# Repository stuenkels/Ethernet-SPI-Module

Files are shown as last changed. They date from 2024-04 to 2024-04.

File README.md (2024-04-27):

# Ethernet SPI Module based on the ENC28J60 IC
Validating my ethernet hardware design. I will use this ethernet board layout in a much larger project, just wanted to test my design and make sure it works.

This board was manufactured by PCBWay, I had it produced for free. I recomend PCBWay to anyone needing PCB or even PCBA production services. Go to pcbway.com for more details. 

## 3d View
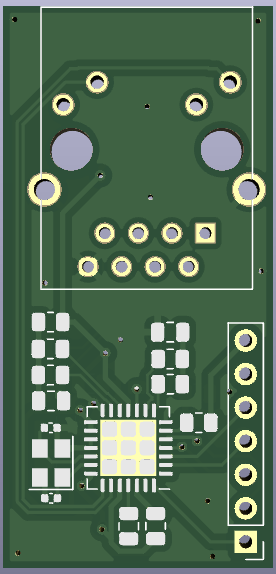
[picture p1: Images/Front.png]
Front

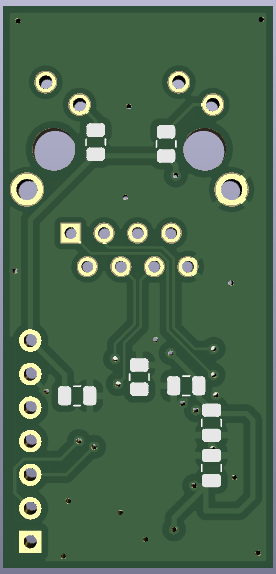
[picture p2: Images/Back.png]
Back


## Finished board
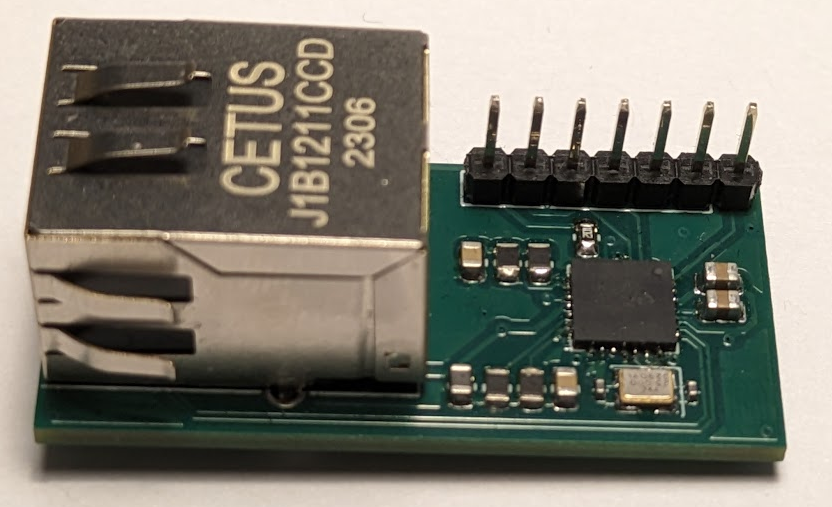
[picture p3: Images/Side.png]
pcbSide

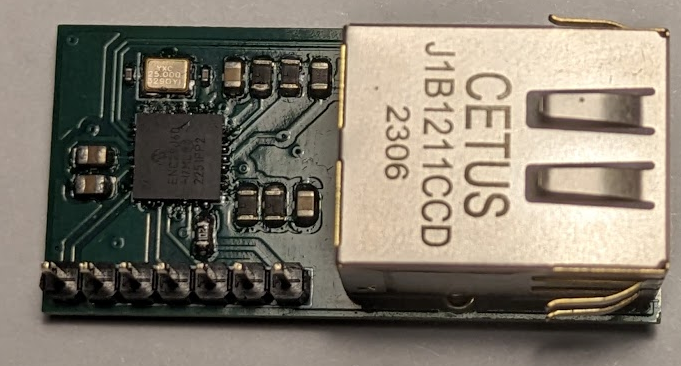
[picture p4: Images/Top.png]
pcbTop


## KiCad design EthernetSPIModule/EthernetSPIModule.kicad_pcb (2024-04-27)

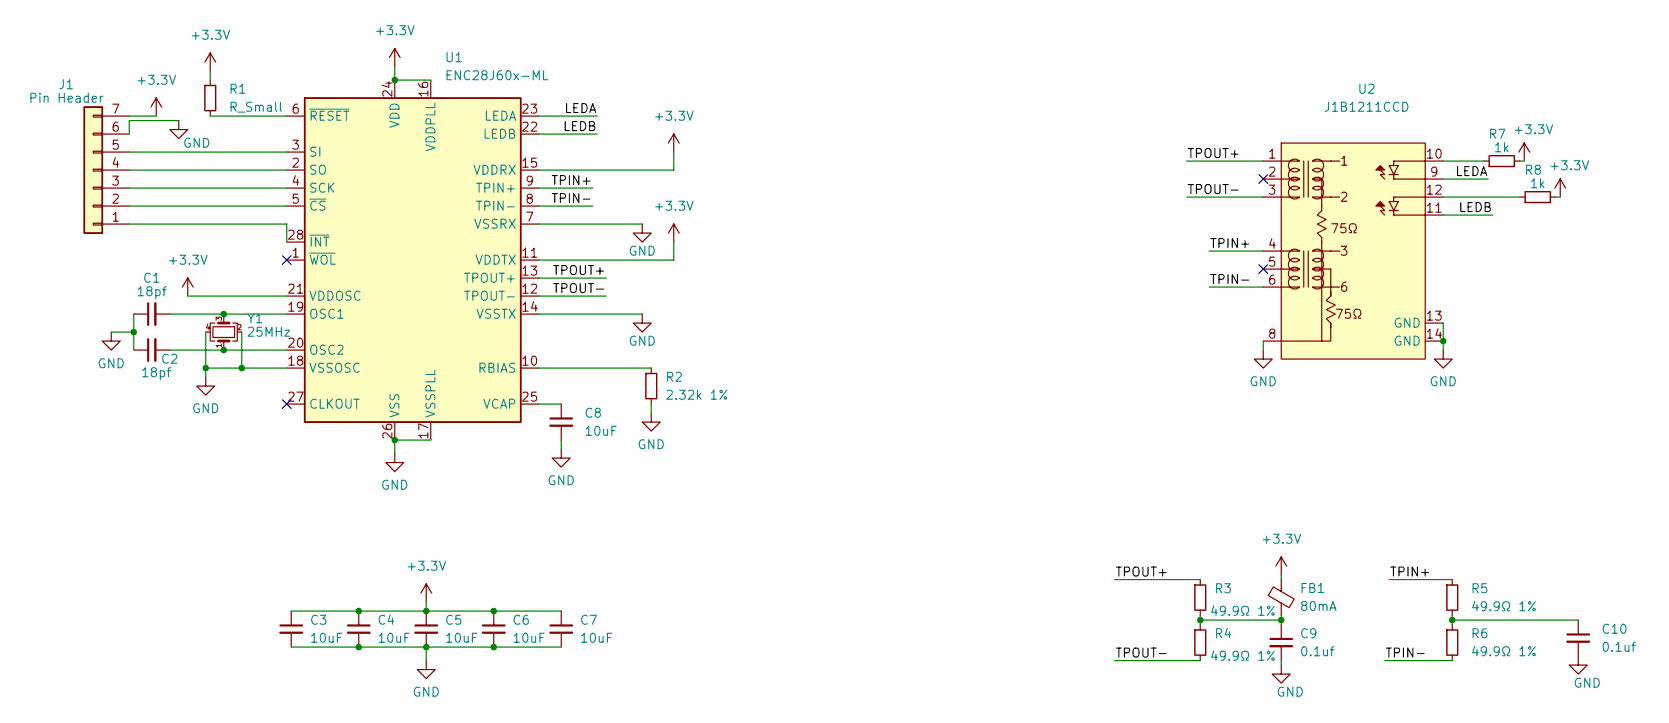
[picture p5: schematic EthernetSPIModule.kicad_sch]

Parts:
C1, C2: 18pf; C_0402_1005Metric
C3, C4, C5, C6, C7, C8: 10uF; C_0805_2012Metric
C9, C10: 0.1uf; C_0805_2012Metric
FB1: 80mA; R_0805_2012Metric
J1: Pin Header; PinHeader_1x07_P2.54mm_Vertical
R1: R_Small; R_0805_2012Metric
R2: 2.32k 1%; R_0805_2012Metric
R3, R4, R5, R6: 49.9Ω 1%; R_0805_2012Metric
R7, R8: 1k; R_0805_2012Metric
U1: ENC28J60x-ML; QFN-28-1EP_6x6mm_P0.65mm_EP4.25x4.25mm
U2: J1B1211CCD
Y1: 25MHz; Crystal_SMD_3225-4Pin_3.2x2.5mm

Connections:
+3.3V: C3.1, C4.1, C5.1, C6.1, C7.1, FB1.1, J1.7, R1.1, R7.2, R8.2, U1.11 (VDDTX), U1.15 (VDDRX), U1.16 (VDDPLL), U1.21 (VDDOSC), U1.24 (VDD)
/LEDA: U1.23 (LEDA), U2.9
/LEDB: U1.22 (LEDB), U2.11
/TPIN+: R5.1, U1.9 (TPIN+), U2.4
/TPIN-: R6.2, U1.8 (TPIN-), U2.6
/TPOUT+: R3.1, U1.13 (TPOUT+), U2.1
/TPOUT-: R4.2, U1.12 (TPOUT-), U2.3
unnamed: C1.2, U1.19 (OSC1), Y1.3
unnamed: C2.2, U1.20 (OSC2), Y1.1
unnamed: C8.1, U1.25 (VCAP)
unnamed: C9.1, FB1.2, R3.2, R4.1
unnamed: C10.1, R5.2, R6.1
unnamed: J1.1, U1.28 (~INT)
unnamed: J1.2, U1.5 (~CS)
unnamed: J1.3, U1.4 (SCK)
unnamed: J1.4, U1.2 (SO)
unnamed: J1.5, U1.3 (SI)
unnamed: R1.2, U1.6 (~RESET)
unnamed: R2.1, U1.10 (RBIAS)
unnamed: R7.1, U2.10
unnamed: R8.1, U2.12

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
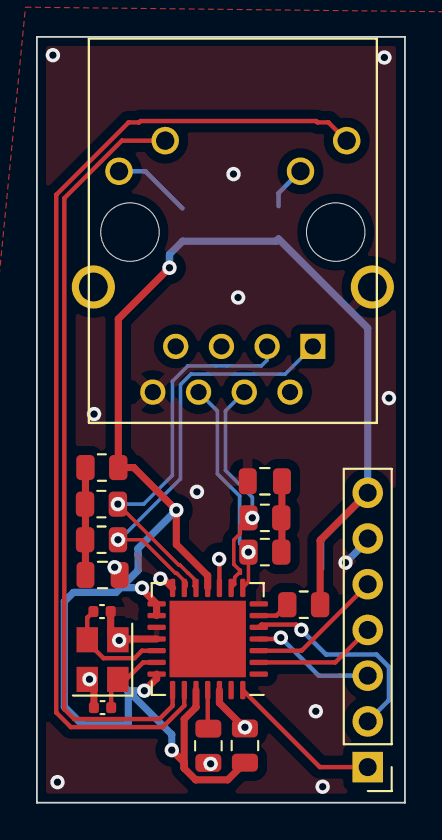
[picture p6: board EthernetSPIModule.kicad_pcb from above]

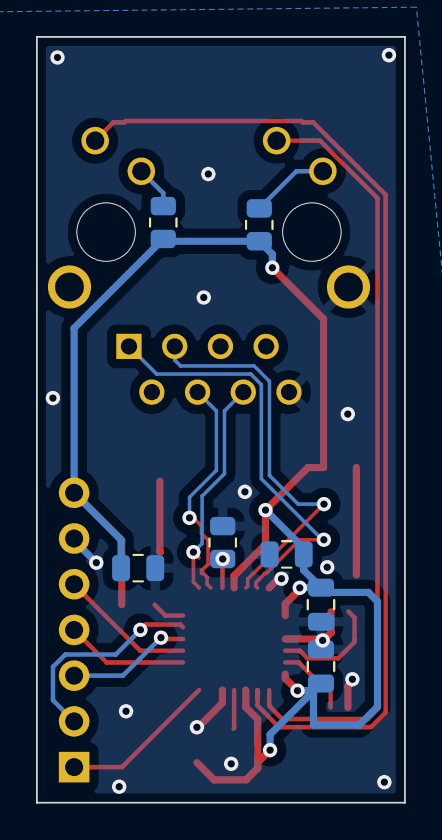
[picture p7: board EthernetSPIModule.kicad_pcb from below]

Board: 2 copper layers, 20.4 x 42.5 mm, 23 parts (7 on the bottom side), 22 nets.
